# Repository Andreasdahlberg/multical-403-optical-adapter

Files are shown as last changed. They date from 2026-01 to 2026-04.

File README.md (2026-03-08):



# Optical Adapter for Multical 403

## Table of Contents
1. [Introduction](#introduction)
2. [Features](#features)
3. [Assembly Instructions](#assembly-instructions)
4. [Software](#software)
5. [Usage](#usage)
6. [Troubleshooting](#troubleshooting)

## Introduction

This project provides an optical adapter designed for the Kamstrup Multical 403 heat meter, allowing you to interface with it via serial communication.

**⚠️ WARNING: This project is work in progress and currently untested. Use at your own risk.**

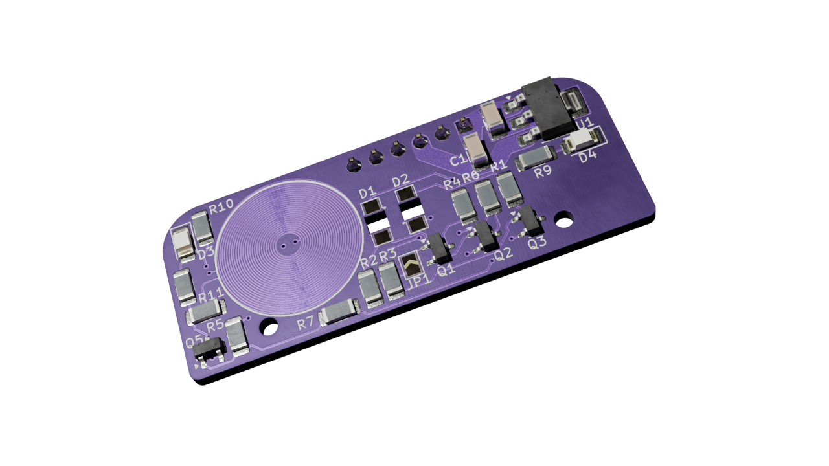
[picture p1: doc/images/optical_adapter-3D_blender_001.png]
PCB


## Features
* On demand activation of the Multical optical interface to reduce power consumption.
* Powered with 5V DC via USB or external power supply.
* Compatible with 3.3V FTDI USB cable.

## Assembly Instructions

### PCB Verification

Before soldering the components, it is recommended to perform the following checks on the PCB to
ensure there are no manufacturing defects:

1. Verify the coil resistance, this can be done by measuring the resistance between the pads
    connected to the coil on the two coil resistors (R10 and R11). The expected resistance should
    be around 18Ω(assuming OSHPark standard 4-layer stackup).

1. Check for short circuits between the 5V, 3V3 and GND pads. 5V and GND is available on the pin
    header while 3V3 is available on the voltage regulator output. There should be no continuity
    between these pads.

### Assembly

1. Solder the components onto the PCB according to the provided BOM and PCB layout. Note that the pin
    header should be soldered on the bottom side of the PCB, while all other components should be
    soldered on the top side. Check out the interactive BOM for component placement and reference
    designators.

    > Tip: Start with the power supply components (voltage regulator, capacitors, and resistors) to
    > ensure the board is powered correctly before soldering the remaining components.

1. Close the J1 solder bridge, it should only be open for testing purposes.

### Mounting

1. Connect a 3.3V FTDI USB cable to the pin header, ensuring the correct orientation. The board is
    designed to be powered by the 5V from the FTDI cable.

1. Mount the optical adapter onto the Multical 403 heat meter's optical interface, the guide holes
    on the PCB should align with the pins on the heat meter. Use double-sided tape on the back of
    the PCB to secure it in place if necessary.

### Bill of Materials

[BOM](https://andreasdahlberg.github.io/multical-403-optical-adapter/bom/optical_adapter-bom.html)

[Interactive BOM](https://andreasdahlberg.github.io/multical-403-optical-adapter/bom/optical_adapter-ibom.html)

## Software

🚧 Work in progress

There is currently no specific software available for interfacing with the optical adapter but
existing tools, such as [PyKMP](https://github.com/gertvdijk/PyKMP) should work. One exception is
the activation of the optical interface, which will require custom code to toggle the activation
pin on the adapter.

## Usage

🚧 Work in progress

## Troubleshooting

🚧 Work in progress

## License

This project is released as **Open Source Hardware** under the [CERN Open Hardware License v2](LICENSE). You are free to use, modify, manufacture, and distribute this hardware, provided you comply with the terms of the license.

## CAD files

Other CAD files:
pcb/pcb_outline.FCStd

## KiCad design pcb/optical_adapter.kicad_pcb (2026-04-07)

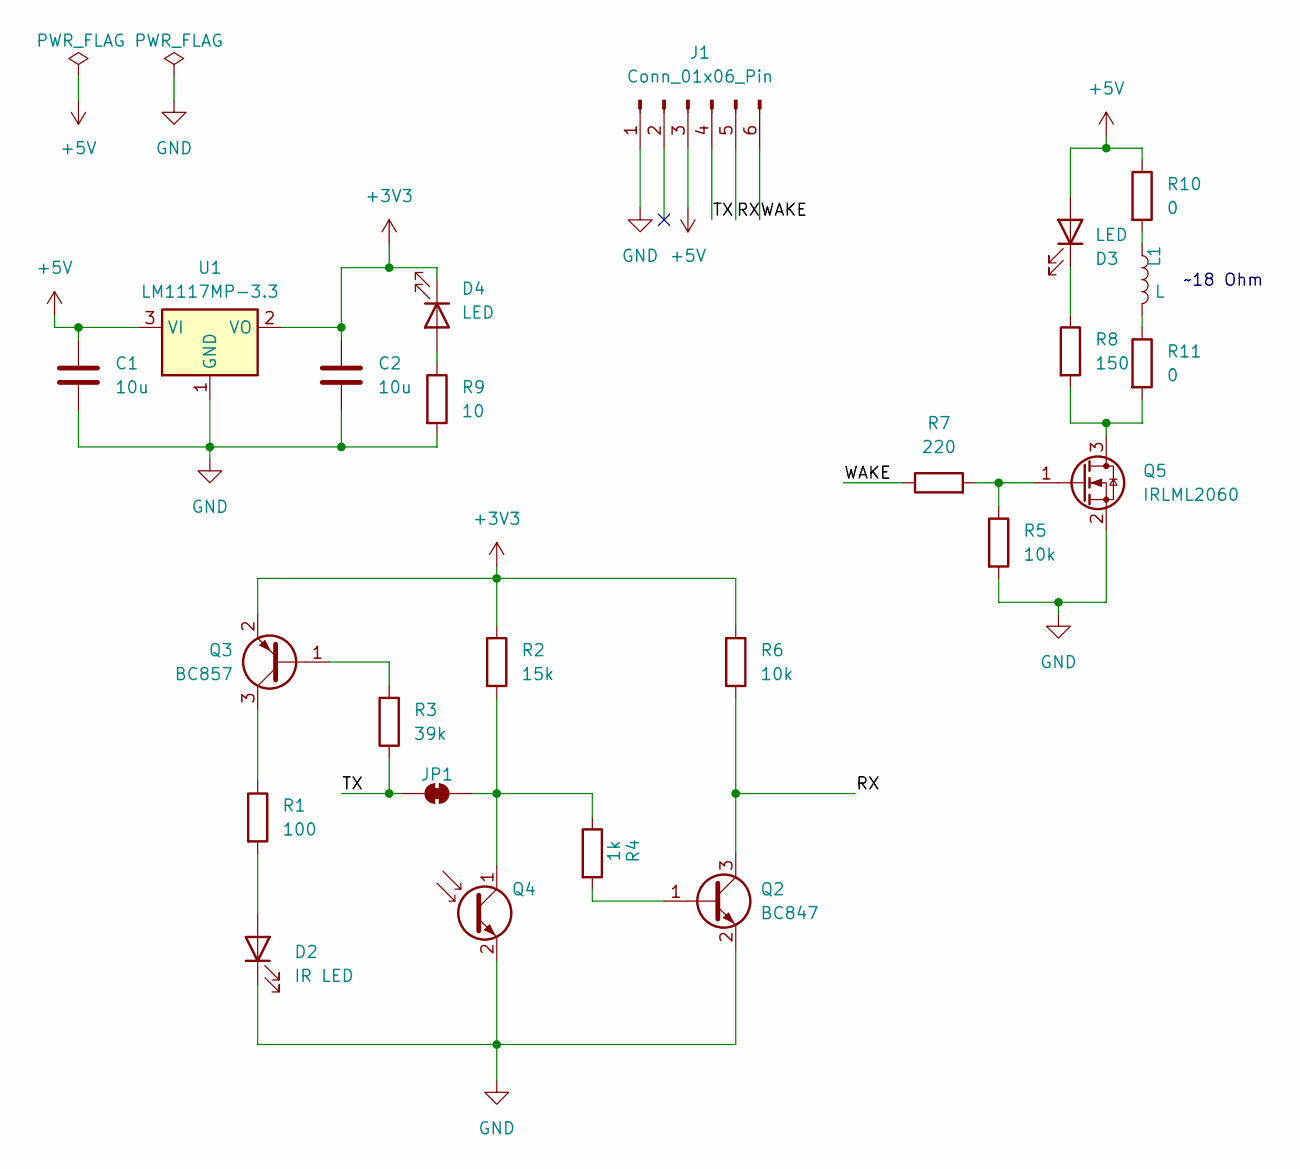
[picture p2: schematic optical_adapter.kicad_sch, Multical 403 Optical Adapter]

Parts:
C1, C2: 10u; C_1206_3216Metric_Pad1.33x1.80mm_HandSolder; MOUSERNO 74-TR3A106K010C1000
D2: IR LED; kingbright_heli_r; MOUSERNO 604-APTR3216F3C
D3: LED; LED_1206_3216Metric_Pad1.42x1.75mm_HandSolder; MOUSERNO 710-150120AS75000
D4: LED; LED_1206_3216Metric_Pad1.42x1.75mm_HandSolder; MOUSERNO 710-150120GS75000
J1: Conn_01x06_Pin; PinHeader_1x06_P2.54mm_Vertical; MOUSERNO 649-68001-406HLF
JP1: SolderJumper_2_Bridged; SolderJumper-2_P1.3mm_Open_TrianglePad1.0x1.5mm
L1: L; 4l_26_turn_16_dia_5_mil
Q2: BC847; SOT-23; MOUSERNO 863-BC847CLT1G
Q3: BC857; SOT-23; MOUSERNO 863-BC857CLT1G
Q4: Q_Photo_NPN; kingbright_heli_r; MOUSERNO 604-APTR3216P3BT
Q5: IRLML2060; SOT-23; MOUSERNO 942-IRLML2060TRPBF
R1: 100; R_1206_3216Metric_Pad1.30x1.75mm_HandSolder; MOUSERNO 71-CRCW1206J-100-E3
R2: 15k; R_1206_3216Metric_Pad1.30x1.75mm_HandSolder; MOUSERNO 71-CRCW1206J-15K-E3
R3: 39k; R_1206_3216Metric_Pad1.30x1.75mm_HandSolder; MOUSERNO 71-CRCW1206J-39K-E3
R4: 1k; R_1206_3216Metric_Pad1.30x1.75mm_HandSolder; MOUSERNO 71-CRCW1206J-15K-E3
R5, R6: 10k; R_1206_3216Metric_Pad1.30x1.75mm_HandSolder; MOUSERNO 71-CRCW1206J-10K-E3
R7: 220; R_1206_3216Metric_Pad1.30x1.75mm_HandSolder; MOUSERNO 71-CRCW1206J-220-E3
R8: 150; R_1206_3216Metric_Pad1.30x1.75mm_HandSolder; MOUSERNO 71-CRCW1206J-150-E3
R9: 10; R_1206_3216Metric_Pad1.30x1.75mm_HandSolder; MOUSERNO 71-CRCW1206J-10-E3
R10, R11: 0; R_1206_3216Metric_Pad1.30x1.75mm_HandSolder; MOUSERNO 71-CRCW12060000ZSTC
U1: LM1117MP-3.3; SOT-223-3_TabPin2; MOUSERNO 926-LM1117MP-3.3NOPB

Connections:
+3V3: C2.1, D4.1 (K), Q3.2 (E), R2.1, R6.1, U1.2 (VO)
+5V: C1.1, D3.2 (A), J1.3, R10.1, U1.3 (VI)
/RX: J1.5, Q2.3 (C), R6.2
/TX: J1.4, JP1.1 (A), R3.1
/WAKE: J1.6, R7.1
GND: C1.2, C2.2, D2.1 (K), J1.1, Q2.2 (E), Q4.2 (E), Q5.2 (S), R5.2, R9.2, U1.1 (GND)
unnamed: D2.2 (A), R1.2
unnamed: D3.1 (K), R8.1
unnamed: D4.2 (A), R9.1
unnamed: JP1.2 (B), Q4.1 (C), R2.2, R4.1
unnamed: L1.1, R10.2
unnamed: L1.2, R11.1
unnamed: Q2.1 (B), R4.2
unnamed: Q3.1 (B), R3.2
unnamed: Q3.3 (C), R1.1
unnamed: Q5.3 (D), R8.2, R11.2
unnamed: Q5.1 (G), R5.1, R7.2

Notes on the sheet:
~18 Ohm

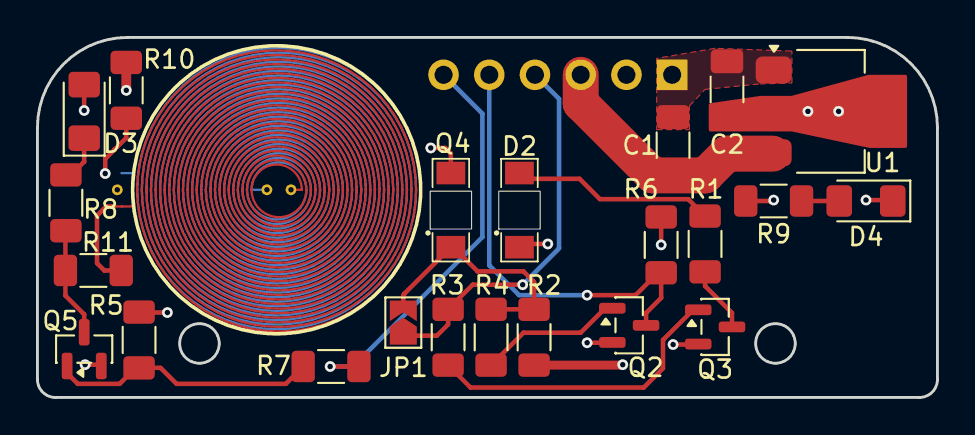
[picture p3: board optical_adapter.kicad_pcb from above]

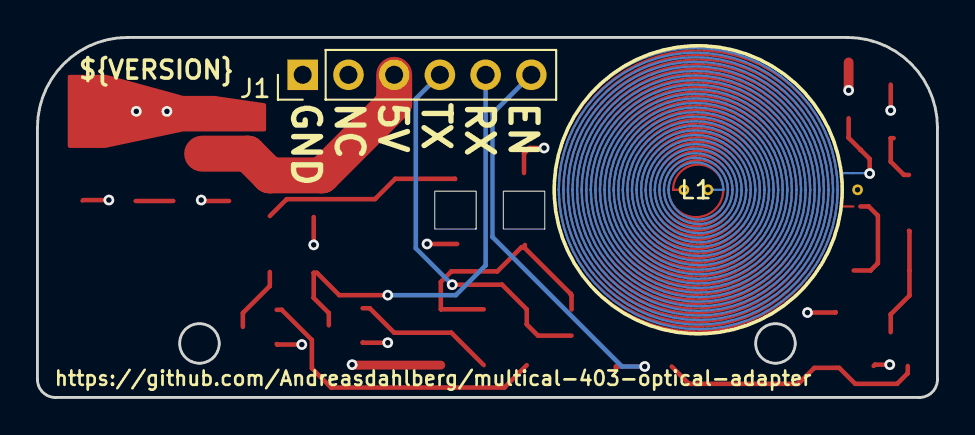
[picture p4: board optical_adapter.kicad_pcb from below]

Board: 4 copper layers, 50.0 x 20.0 mm, 24 parts (2 on the bottom side), 17 nets.

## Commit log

2025-01-10 Add PCB shape design file
    [board.FCStd]
2025-01-10 Add Kicad project
    [optical_adapter.kicad_pcb, optical_adapter.kicad_sch]
2025-01-10 Rename PCB outline file
    [pcb_outline.FCStd]
2025-01-10 Restructure pcb directory
    [optical_adapter.kicad_pcb, optical_adapter.kicad_sch]
2025-01-10 Use kicad 8 image for Kibot CI workflows
2025-01-13 Add PCB coil footprint
    [optical_adapter.kicad_pcb, optical_adapter.kicad_sch]
2025-01-13 Add power supply circuit
    [optical_adapter.kicad_sch]
2025-01-13 Add IR RX/TX circuit
    [optical_adapter.kicad_sch]
2025-01-13 Rough PCB component layout
    [optical_adapter.kicad_pcb, optical_adapter.kicad_sch]
2025-01-14 Add coil driver circuit
    [optical_adapter.kicad_sch]
2025-01-14 Add power LED to 3V3 rail
    [optical_adapter.kicad_sch]
2025-01-14 Update layout with coil driver components
    [optical_adapter.kicad_pcb]
2025-01-18 Add 0 Ohms resistors to the coil
    They make it possible to limit the current if needed and make
    it easier to patch, e.g. change direction.
    [optical_adapter.kicad_sch]
2025-01-18 Remove solder bridge between VBUS and +5V
    [optical_adapter.kicad_sch]
2025-01-18 Route power supply
    [optical_adapter.kicad_pcb]
2025-01-21 Update PCB layout
    All traces are routed.
    [optical_adapter.kicad_pcb]
2025-08-24 Update KiCad files to version 9
    [optical_adapter.kicad_pcb, optical_adapter.kicad_sch]
2025-08-24 Use KiCad 9 container for KiBot workflow
2025-08-24 Update mismatched footprints
    [optical_adapter.kicad_pcb]
2025-12-25 Update project settings
    [optical_adapter.kicad_pcb]
2025-12-27 Add part numbers to BOM
    [optical_adapter.kicad_sch]
2025-12-27 Add solder bridge between TX and RX circuit
    [optical_adapter.kicad_pcb, optical_adapter.kicad_sch]
2025-12-29 Fix the coil active LED
    Changed to 150 Ohm to better suite the amber LED and fix incorrect
    rotation.
    [optical_adapter.kicad_pcb, optical_adapter.kicad_sch]
2025-12-29 Update symbols
    [optical_adapter.kicad_pcb, optical_adapter.kicad_sch]
2025-12-29 Add new PCB coil footprint
2025-12-29 Move the coil wake up signal to RTS
    [optical_adapter.kicad_pcb, optical_adapter.kicad_sch]
2025-12-29 Update kingbright LED footprint
    Adjusted the silkscreen so that it does not overlap with the pads.
    [optical_adapter.kicad_pcb]
2025-12-29 Add missing datasheet link for the IR-LED
    [optical_adapter.kicad_sch]
2026-01-07 Update README
    Added a WIP warning and an image of the PCB.
2026-01-27 Fix DRC warnings
    [optical_adapter.kicad_pcb, optical_adapter.kicad_sch]
2026-01-27 Update footprints
    [optical_adapter.kicad_pcb]
2026-01-27 Add BOM links to README
2026-03-06 Fix incorrect datasheet URL
    [optical_adapter.kicad_sch]
2026-03-06 Add ignore rule for hole clearance
    The coil generator plugin created the holes that triggered the warnings,
    but it should be ok to manufacture.
    [optical_adapter.kicad_pcb]
2026-03-06 Increase radius of guide holes
    This required the coil to be moved upwards to make place for the
    bigger holes.
    [optical_adapter.kicad_pcb]
2026-03-06 Add OSHW logo to the PCB
    [optical_adapter.kicad_pcb]
2026-03-07 Use variable for board version
    [optical_adapter.kicad_pcb]
2026-03-07 Add release workflow
    This workflow will package a release on tags with the Kicad files.
2026-03-07 Update version in PCB file on release
2026-03-07 Update README
    Added assembly instructions and software info.
2026-04-07 Fix #4
    Swap silkscreen designator for R1 and R6
    [optical_adapter.kicad_pcb]
2026-04-07 Add datasheet for power LED
    [optical_adapter.kicad_sch]
2026-04-07 Fix #1
    Increase the value of the power LED resistor since the LED was to
    bright.
    [optical_adapter.kicad_pcb, optical_adapter.kicad_sch]
2026-04-07 Fix #5
    Change D1 to Q4(phototransistor)
    [optical_adapter.kicad_pcb, optical_adapter.kicad_sch]
2026-04-07 Redesign RX circuit
    [optical_adapter.kicad_pcb, optical_adapter.kicad_sch]
